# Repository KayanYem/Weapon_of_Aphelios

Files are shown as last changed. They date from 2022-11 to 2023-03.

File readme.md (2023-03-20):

# Weapon_of_Aphelios

> ：这个名字好中二的样子
> 
> ：就是很中二的东西
> 而且“美而无用”

**硬件部分：** WS2812 LED灯（X5），使用STM32芯片，按键（红、蓝）。

**实现功能：**
* 红色按键：最右边的灯移到最左，其余四个依次向右移一位。
* 蓝色按键：最右边的灯不动，右边第二个灯移到最左，其余四个依次向右移一位。

**展示**

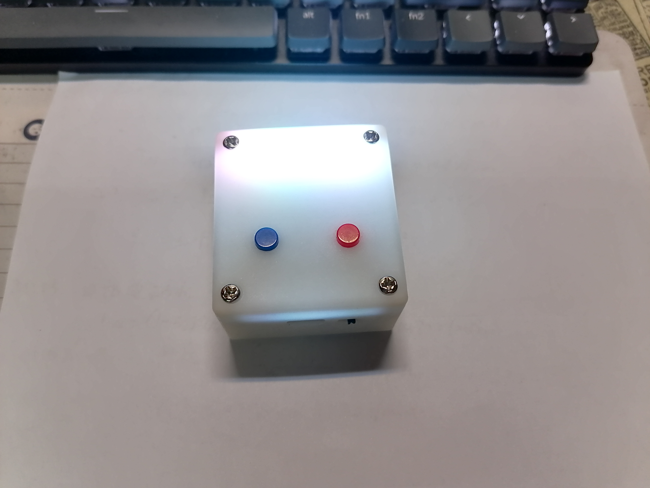
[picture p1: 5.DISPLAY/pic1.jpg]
图1

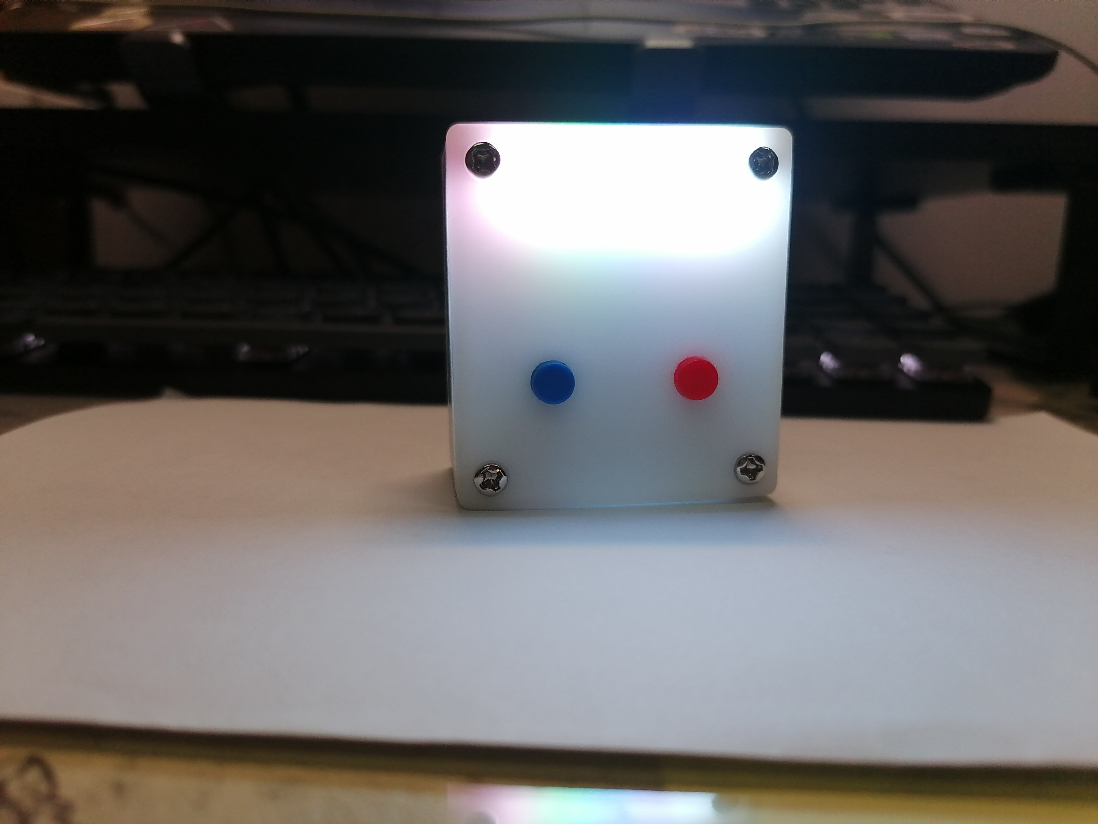
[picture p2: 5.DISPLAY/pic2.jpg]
图2

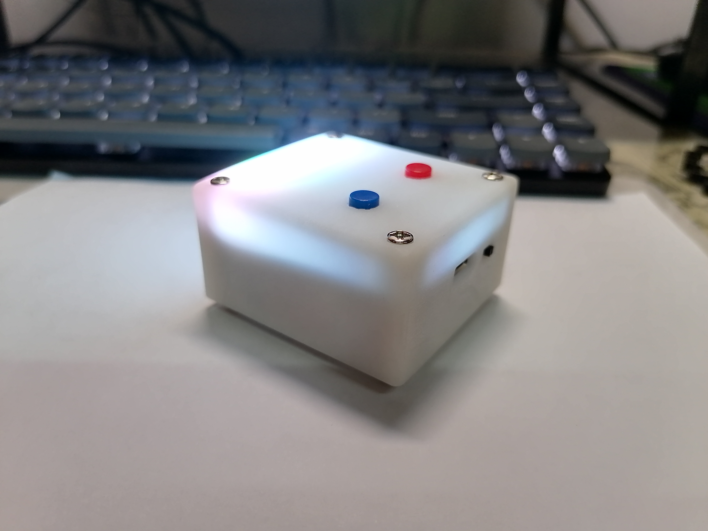
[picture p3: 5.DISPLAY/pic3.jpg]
图3

video

```
230225 调试
1. 需要修改硬件电路
2. 购买的按钮与设计的不同（已修改
3. LED灯电路有误，电容应该接电源和接地（已修改
4. 考虑是否更换供电方案（没有更换

230320 完整装配
1. 3D打印壳体透光效果不太好
2. 整体装配后体积较大
3. 壳体设计考虑不足导致装配麻烦
```

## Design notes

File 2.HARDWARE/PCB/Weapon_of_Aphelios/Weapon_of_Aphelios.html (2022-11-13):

Altium customize

# Board Information Report

Date: | | 2022/11/13
Time: | | 1:08:02
Elapsed Time: | | 00:00:00
Filename: | | E:\My_Project\Weapon_of_Aphelios\2.HARDWARE\PCB\Weapon_of_Aphelios\Weapon_of_Aphelios.PcbDoc
Units: | | mmmils

## Contents

Contents

Board Specification

General

Routing

Routing Information

Layer Information

Layer Information

Drill Pairs

Copper Area

Copper Area

Board Holes

Non-Plated Hole Size

Plated Hole Size

Board Slots

Non-Plated Slot Size

Plated Slot Size

Board Square Holes

Non-Plated Square Hole Size

Plated Square Hole Size

Other

Top Layer Annular Ring Size

Mid Layer Annular Ring Size

Bottom Layer Annular Ring Size

Pad Solder Mask

Pad Paste Mask

Pad Pwr/Gnd Expansion

Pad Relief Conductor Width

Pad Relief Air Gap

Pad Relief Entries

Via Solder Mask

Via Pwr/Gnd Expansion

Track Width

Arc Line Width

Arc Radius

Arc Degrees

Text Height

Text Width

Net Track Width

Net Via Size

## Board Specification

General
Board Size | 1771.654mils x 1968.504mils
Components on board | 49

Back to top

## Routing

Routing Information
Routing completion | 100.00%
Connections | 117
Connections routed | 117
Connections remaining | 0

Back to top

## Layer Information

Layer | Arcs | Pads | Vias | Tracks | Texts | Fills | Regions | ComponentBodies
Top Layer | 0 | 120 | 0 | 175 | 0 | 0 | 34 | 0
Bottom Layer | 0 | 47 | 0 | 58 | 0 | 0 | 15 | 0
Mechanical 1 | 4 | 0 | 0 | 10 | 0 | 0 | 0 | 41
Mechanical 4 | 0 | 0 | 0 | 0 | 0 | 0 | 2 | 0
Mechanical 5 | 0 | 0 | 0 | 0 | 0 | 0 | 12 | 0
Mechanical 6 | 8 | 0 | 0 | 0 | 0 | 0 | 20 | 0
Mechanical 13 | 1 | 0 | 0 | 4 | 0 | 0 | 0 | 1
Mechanical 15 | 1 | 0 | 0 | 34 | 0 | 0 | 49 | 0
Multi-Layer | 0 | 19 | 53 | 0 | 0 | 0 | 5 | 0
Top Paste | 0 | 0 | 0 | 0 | 0 | 0 | 0 | 0
Top Overlay | 64 | 0 | 0 | 208 | 69 | 0 | 5 | 0
Top Solder | 0 | 0 | 0 | 0 | 0 | 0 | 0 | 0
Bottom Solder | 0 | 0 | 0 | 0 | 0 | 0 | 0 | 0
Bottom Overlay | 31 | 0 | 0 | 183 | 43 | 19 | 0 | 0
Bottom Paste | 0 | 0 | 0 | 0 | 0 | 0 | 0 | 0
Drill Guide | 0 | 0 | 0 | 0 | 0 | 0 | 0 | 0
Keep-Out Layer | 0 | 0 | 0 | 0 | 0 | 0 | 0 | 0
Drill Drawing | 0 | 0 | 0 | 0 | 0 | 0 | 0 | 0
Total | 109 | 186 | 53 | 672 | 112 | 19 | 142 | 42

Back to top

Drill Pairs | Vias
Top Layer - Bottom Layer | 53
Total | 53

Back to top

## Copper Area

Layer | Sq.In. | Sq.MM. | Percent of layer
Top Layer | 2.235 | 1442.114 | 64%
Bottom Layer | 2.686 | 1732.591 | 77%
Total | 4.921 | 3174.705

Back to top

## Board Holes

Non-Plated Hole Size | Pads | Vias
Total | 0 | 0

Back to top

Plated Hole Size | Pads | Vias
0mils | 167 | 0
12mils | 0 | 4
15mils | 0 | 49
35.433mils | 8 | 0
39.37mils | 5 | 0
Total | 180 | 53

Back to top

## Board Slots

Non-Plated Slot Size / Length | Pads
Total | 0

Back to top

Plated Slot Size / Length | Pads
23.62mil / 55.12mil | 2
23.62mil / 66.93mil | 2
39.37mil / 70.866mil | 2
Total | 6

Back to top

## Board Square Holes

Non-Plated Square Hole Size | Pads
Total | 0

Back to top

Plated Square Hole Size | Pads
Total | 0

Back to top

## Other

Top Layer Annular Ring Size | Count
5mils | 49
12mils | 4
15.75mils | 4
23.62mils | 3
23.622mils | 8
31.496mils | 2
78.74mils | 2
Total | 72

Back to top

Mid Layer Annular Ring Size | Count
5mils | 49
12mils | 4
15.75mils | 4
23.62mils | 3
23.622mils | 8
31.496mils | 2
78.74mils | 2
Total | 72

Back to top

Bottom Layer Annular Ring Size | Count
5mils | 49
12mils | 4
15.75mils | 4
23.62mils | 3
23.622mils | 8
31.496mils | 2
78.74mils | 2
Total | 72

Back to top

Pad Solder Mask | Count
2mils | 31
4mils | 155
Total | 186

Back to top

Pad Paste Mask | Count
0mils | 186
Total | 186

Back to top

Pad Pwr/Gnd Expansion | Count
20mils | 186
Total | 186

Back to top

Pad Relief Conductor Width | Count
20mils | 186
Total | 186

Back to top

Pad Relief Air Gap | Count
10mils | 186
Total | 186

Back to top

Pad Relief Entries | Count
4 | 186
Total | 186

Back to top

Via Solder Mask | Count
0mils | 4
4mils | 49
Total | 53

Back to top

Via Pwr/Gnd Expansion | Count
20mils | 53
Total | 53

Back to top

Track Width | Count
2mils | 28
3.937mils | 10
5.984mils | 2
6mils | 14
7.874mils | 128
8mils | 29
9.843mils | 12
10mils | 403
20mils | 19
30mils | 27
Total | 672

Back to top

Arc Line Width | Count
2.362mils | 1
3.937mils | 2
6mils | 1
7.874mils | 80
9.449mils | 5
9.843mils | 1
10mils | 15
11.8mils | 3
23.622mils | 1
Total | 109

Back to top

Arc Radius | Count
1.18mils | 1
1.97mils | 1
3.94mils | 5
4.72mils | 5
4.921mils | 1
5mils | 1
5.9mils | 3
11.811mils | 1
17.03mils | 20
17.564mils | 20
19.105mils | 20
19.685mils | 1
20.506mils | 20
59.06mils | 5
78.74mils | 4
98.425mils | 1
Total | 109

Back to top

Arc Degrees | Count
90 | 80
360 | 29
Total | 109

Back to top

Text Height | Count
30mils | 105
47.244mils | 1
60mils | 6
Total | 112

Back to top

Text Width | Count
9.843mils | 1
10mils | 111
Total | 112

Back to top

Net Track Width | Count
10mils | 29
Total | 29

Back to top

Net Via Size | Count
20mils | 29
Total | 29

Back to top

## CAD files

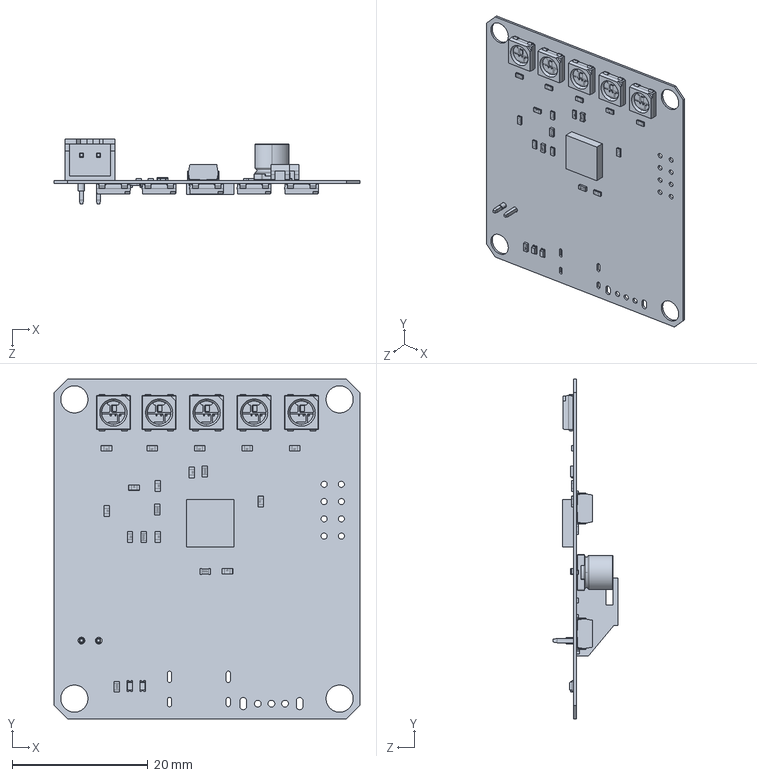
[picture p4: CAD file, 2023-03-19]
4.CAD_MODEL/Assembly.SLDASM
45.0 x 50.0 x 9.50 mm

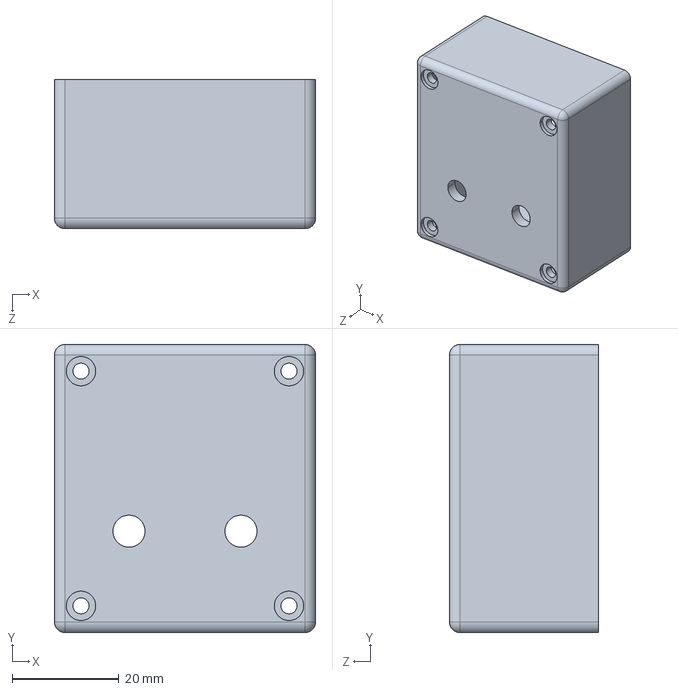
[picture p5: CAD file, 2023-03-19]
4.CAD_MODEL/cover_1.STEP
49.0 x 54.0 x 28.0 mm

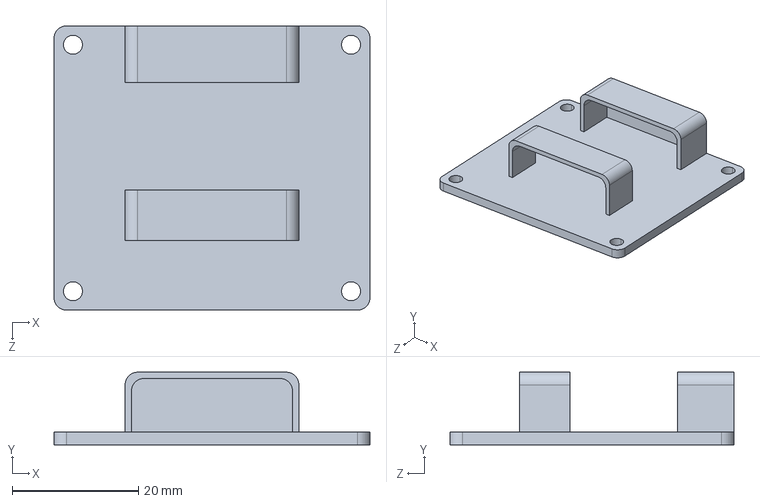
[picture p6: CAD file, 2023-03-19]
4.CAD_MODEL/cover_2.STEP
50.0 x 11.5 x 45.0 mm

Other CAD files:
4.CAD_MODEL/Weapon_of_Aphelios.step
4.CAD_MODEL/cover_1.SLDPRT
4.CAD_MODEL/cover_2.SLDPRT

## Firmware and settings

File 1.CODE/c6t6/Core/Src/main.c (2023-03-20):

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
/* Includes ------------------------------------------------------------------*/
#include "main.h"
#include "dma.h"
#include "tim.h"
#include "usart.h"
#include "gpio.h"

/* USER CODE BEGIN Includes */
#include "stdio.h"
#include "WS2812B.h"
#include "stmflash.h"
/* USER CODE END Includes */

/* USER CODE BEGIN PTD */
#define SAVE_MARK_ADDR 0x08004000		//fresh 更新标记
#define SAVE_ADDR 0x08004200				//fresh 写入

#define LED_NUM		5
/* USER CODE END PTD */


/* USER CODE BEGIN PV */

uint32_t t;
uint16_t i,j,temp[3], flag=0;

uint16_t flash_init_temp[2]={0};
uint16_t SAVE_MARK[2] = {11,11};
uint16_t SAVE_BUFFER[24];

//自定义rgb颜色数组			
/****RGB颜色表****
//uint8_t white[3] = {255,255,255};
//uint8_t red[3] = {255,0,0};
//uint8_t green[3] = {0,255,0};
//uint8_t blue[3] = {0,0,255};
//uint8_t cyan[3] = {0,255,255};
//uint8_t purple[3] = {255,0,255};
//uint8_t yellow[3] = {255,255,0};
//uint8_t orange[3] = {255,97,0};
//uint8_t brown[3] = {128,42,42};
//uint8_t pink[3] = {255,192,203};
//uint8_t D_green[3] = {48,128,20};
//uint8_t D_blue[3] = {25,25,112};
*/

uint8_t change_rgb_init[LED_NUM][3] = {
	{50,225,50},
	{250,50,125},
	{131,71,205},
	{68,117,249},
	{214,235,255}
};

uint8_t change_rgb[LED_NUM][3];

uint8_t rgb0[][3] = {0,0,0};
/* USER CODE END PV */

void SystemClock_Config(void);
/**
  * @brief  The application entry point.
  * @retval int
  */
int main(void)
{
  /* MCU Configuration--------------------------------------------------------*/

  /* Reset of all peripherals, Initializes the Flash interface and the Systick. */
  HAL_Init();

  /* Configure the system clock */
  SystemClock_Config();

  /* Initialize all configured peripherals */
  MX_GPIO_Init();
  MX_DMA_Init();
  MX_TIM2_Init();
  MX_USART1_UART_Init();
  /* USER CODE BEGIN 2 */

   printf("串口打印正常!\r\n");

	//将初始化数据赋值 PWM输出数组 和 flash存储数组
	for(i=0;i<LED_NUM;i++)
	{
		for(j=0;j<3;j++)
		{
			change_rgb[i][j] = change_rgb_init[i][j];
			SAVE_BUFFER[i*3+j] = change_rgb_init[i][j];
		}
	}
	
	//读取判断位
	STMFLASH_Read(SAVE_MARK_ADDR, flash_init_temp, 2);
	printf("%d\t",flash_init_temp[0]);
	printf("%d\r\n",flash_init_temp[1]);
	
	
	//如果写入，则读取flash数据
	if(flash_init_temp[0] == SAVE_MARK[0] && flash_init_temp[1] == SAVE_MARK[1])
	{
		printf("read from flash\r\n");
		STMFLASH_Read(SAVE_ADDR, SAVE_BUFFER, LED_NUM*3);
		for(i=0;i<LED_NUM*3;i++)
		{
			printf("%d ",SAVE_BUFFER[i]);
		}
		printf("\r\n");
		
		for(i=0;i<LED_NUM;i++)
		{
			for(j=0;j<3;j++)
			{
				change_rgb[i][j] = SAVE_BUFFER[i*3+j];
			}
		}
	}
	//如果未写入，则写出初始化数据
	else
	{
		printf("init flash\r\n");
		STMFLASH_Write(SAVE_MARK_ADDR, SAVE_MARK, 2);				//FLASH更新标志位写入
		STMFLASH_Read(SAVE_MARK_ADDR, SAVE_MARK, 2);
		for(i=0;i<2;i++)
		{
			printf("%d ",SAVE_MARK[i]);
		}
		printf("\r\n");
		
		STMFLASH_Write(SAVE_ADDR, SAVE_BUFFER, LED_NUM*3);	//flash颜色数据写入
		STMFLASH_Read(SAVE_ADDR, SAVE_BUFFER, LED_NUM*3);
		for(i=0;i<LED_NUM*3;i++)
		{
			printf("%d ",SAVE_BUFFER[i]);
		}
		printf("\r\n");
	}
	
	//setoff all light
	WS2812_led_send(rgb0,8);
	HAL_Delay(5);
	
	WS2812_ledsingle_send(change_rgb,LED_NUM);
	HAL_Delay(5);
	
  /* USER CODE END 2 */

  /* Infinite loop */
  /* USER CODE BEGIN WHILE */
  while (1)
  {
		
		if(flag == 1)
		{
			for(i=0;i+1<LED_NUM;i++)
			{
				for(j=0;j<3;j++)
				{
					temp[j] = change_rgb[i][j];
					change_rgb[i][j] = change_rgb[i+1][j];
					change_rgb[i+1][j] = temp[j];
				}
			}
			
			WS2812_ledsingle_send(change_rgb,LED_NUM);
			HAL_Delay(200);
			
			//write flash
			for(i=0;i<LED_NUM;i++)
			{
				for(j=0;j<3;j++)
				{
					SAVE_BUFFER[i*3+j] = change_rgb[i][j];
				}
			}
			printf("key1 press \r\n");
			STMFLASH_Write(SAVE_ADDR, SAVE_BUFFER, LED_NUM*3);
//			STMFLASH_Read(SAVE_ADDR, SAVE_BUFFER, LED_NUM*3);
//			for(i=0;i<LED_NUM*3;i++)
//			{
//				printf("%d ",SAVE_BUFFER[i]);
//			}
//			printf("\r\n");
			
			//重置按键标志位
			flag = 0;
		}
		
		if(flag == 2)
		{
			for(i=1;i+1<LED_NUM;i++)
			{
				for(j=0;j<3;j++)
				{
					temp[j] = change_rgb[i][j];
					change_rgb[i][j] = change_rgb[i+1][j];
					change_rgb[i+1][j] = temp[j];
				}
			}
			WS2812_ledsingle_send(change_rgb,LED_NUM);
			HAL_Delay(200);
			
			//write flash
			for(i=0;i<LED_NUM;i++)
			{
				for(j=0;j<3;j++)
				{
					SAVE_BUFFER[i*3+j] = change_rgb[i][j];
				}
			}
			printf("key2 press \r\n");
			STMFLASH_Write(SAVE_ADDR, SAVE_BUFFER, LED_NUM*3);
//			STMFLASH_Read(SAVE_ADDR, SAVE_BUFFER, LED_NUM*3);
//			for(i=0;i<LED_NUM*3;i++)
//			{
//				printf("%d ",SAVE_BUFFER[i]);
//			}
//			printf("\r\n");
			
			//重置按键标志位
			flag = 0;
		}	
		
    /* USER CODE END WHILE */

    /* USER CODE BEGIN 3 */
  }
  /* USER CODE END 3 */
}

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
/* USER CODE BEGIN 4 */

//exterinal break callback
void HAL_GPIO_EXTI_Callback(uint16_t GPIO_Pin)
{
	HAL_Delay(10);
	printf("GPIO_Pin %d \r\n",GPIO_Pin);
//	HAL_GPIO_TogglePin(GPIOC, GPIO_PIN_13);
	//key1 pressed
	if(GPIO_Pin == GPIO_PIN_1){
		flag = 1;
		HAL_GPIO_WritePin(GPIOC, GPIO_PIN_13, GPIO_PIN_SET);
	}
	
	//key2 pressed
	if(GPIO_Pin == GPIO_PIN_2){
		flag = 2;
		HAL_GPIO_WritePin(GPIOC, GPIO_PIN_13, GPIO_PIN_RESET);
	}
}

//PWM callback
void HAL_TIM_PWM_PulseFinishedCallback(TIM_HandleTypeDef *htim)
{
		HAL_TIM_PWM_Stop_DMA(&htim2,TIM_CHANNEL_1);
}

/* USER CODE END 4 */
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


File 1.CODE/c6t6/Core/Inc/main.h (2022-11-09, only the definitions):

#define LED_Pin GPIO_PIN_13
#define LED_GPIO_Port GPIOC
#define KEY1_Pin GPIO_PIN_1
#define KEY1_GPIO_Port GPIOA
#define KEY1_EXTI_IRQn EXTI1_IRQn
#define KEY2_Pin GPIO_PIN_2
#define KEY2_GPIO_Port GPIOA
#define KEY2_EXTI_IRQn EXTI2_IRQn

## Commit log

2022-11-13 add PCB Project
    [Weapon_of_Aphelios.PcbDoc, Weapon_of_Aphelios.PcbLib, Weapon_of_Aphelios.PrjPcb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]
2023-03-09 correct the wrong design
    [Weapon_of_Aphelios.PcbDoc, Weapon_of_Aphelios.PcbLib, Weapon_of_Aphelios.PrjPcb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]
2023-03-19 Add CAD model
    [Assembly.SLDASM, Weapon_of_Aphelios.step, cover_1.SLDPRT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]
2023-03-20 Assembly completed
    [Weapon_of_Aphelios.PcbDoc, Weapon_of_Aphelios.PcbLib, Weapon_of_Aphelios.SCHLIB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]

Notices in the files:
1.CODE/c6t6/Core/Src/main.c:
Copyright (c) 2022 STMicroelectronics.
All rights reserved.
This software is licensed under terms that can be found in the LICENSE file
